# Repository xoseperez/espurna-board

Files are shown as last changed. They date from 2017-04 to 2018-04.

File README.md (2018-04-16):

View this project on [CADLAB.io](https://cadlab.io/node/890). 

# ESPurna Boards

## ESPurna-H

The ESPurna-H board is a custom ESP8266-based smart wall switch. It's singularity is that it's meant to be embedded into the wall behind a standard wall switch, replacing the mechanic switch with a wifi-enabled smart switch.

The board is based on the HLW8012 power monitor IC, the same the Sonoff POW uses.

It features:

* SPDT 10A relay with **NO and NC connections** brought out
* Connections for **external button and notification LED**
* HLW8012 chip for **power monitoring**
* 50x50mm low profile form factor to fit in the wall switch hole

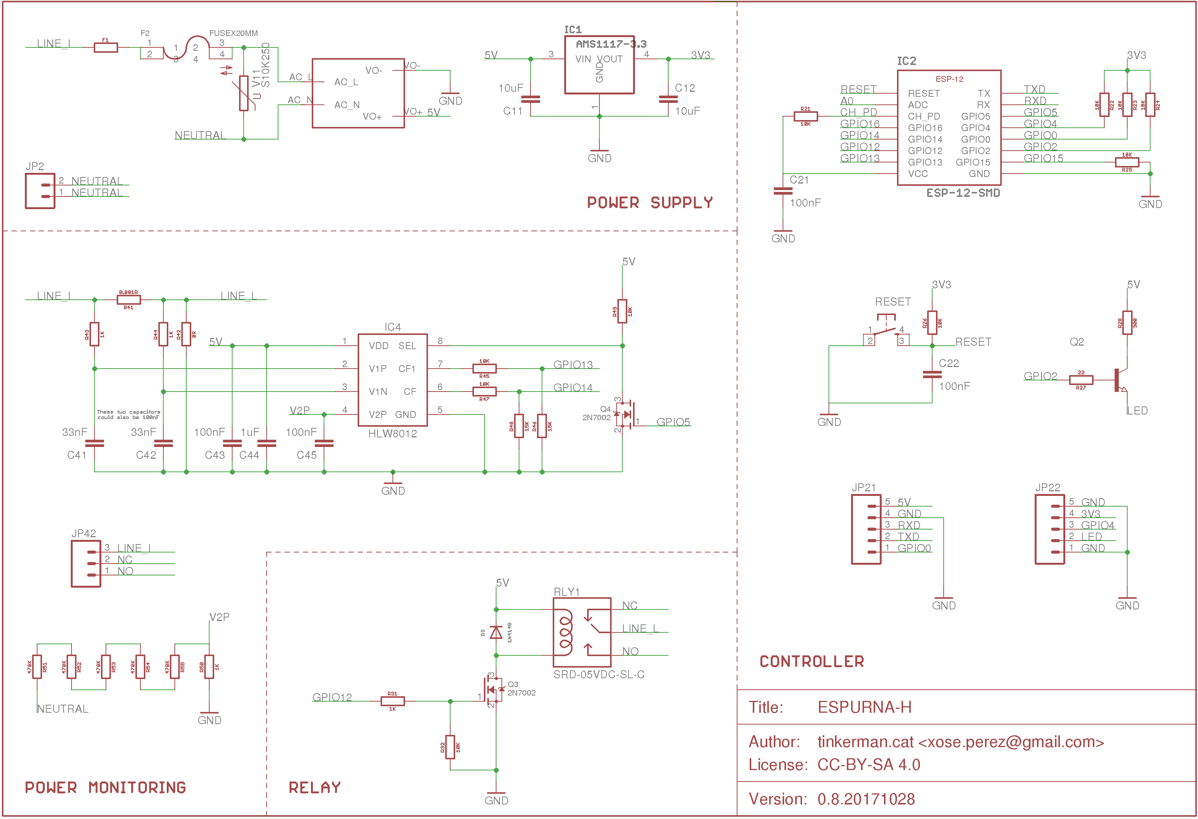
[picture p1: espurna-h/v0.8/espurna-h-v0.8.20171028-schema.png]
ESPurna-H Board - schematic


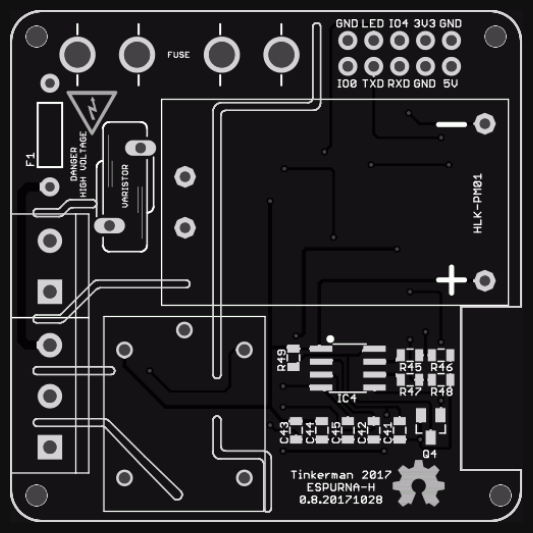
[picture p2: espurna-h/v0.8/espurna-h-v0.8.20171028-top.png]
ESPurna-H Board - layout - top


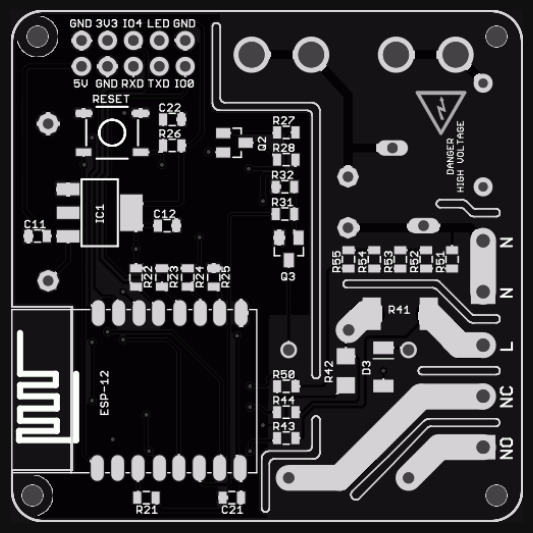
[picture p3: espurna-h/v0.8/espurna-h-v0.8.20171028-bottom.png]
ESPurna-H Board - layout - bottom


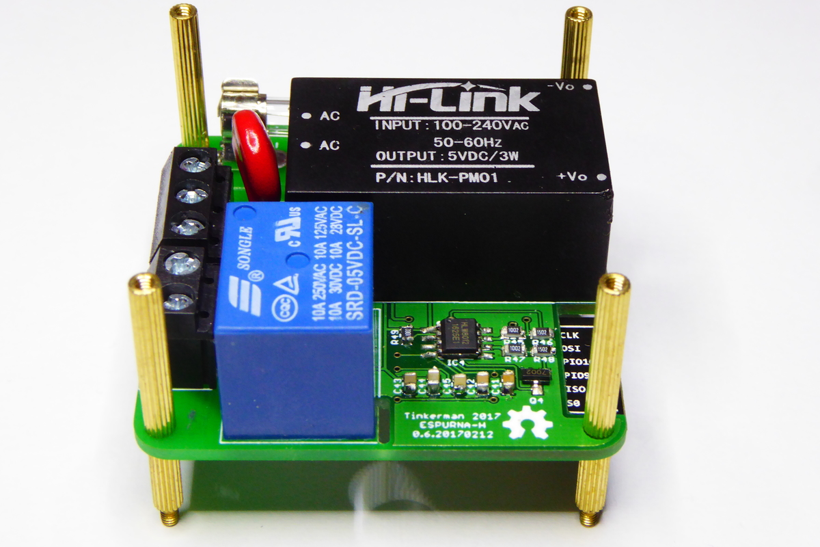
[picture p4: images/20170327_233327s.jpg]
ESPurna-H Board - front view


## Bill of materials

|Item|Location(s)|Buy|Required|Optional <sup>H</sup>|CPU <sup>units</sup>|Total|Total <sup>H</sup>|
|---|---|---|---|---|---|---|---|
|Tinkerman ESPurna-H PCB||[OSH Park](https://oshpark.com/shared_projects/lxVzIaBY)|1||6.50€ <sup>3</sup>|6.50€||
|Ai-Thinker ESP12F|ESP-12|[Aliexpress](http://s.click.aliexpress.com/e/mUZjemI) / [Ebay](https://rover.ebay.com/rover/1/711-53200-19255-0/1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)|1||2.10€ <sup>5</sup>|2.10€||
|Hi-Link HLK-PM01|HLK-PM01|[Aliexpress](http://s.click.aliexpress.com/e/yzVBurN) / [Ebay](https://rover.ebay.com/rover/1/711-53200-19255-0/1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)|1||2.16€ <sup>5</sup>|2.16€||
|Songle SRD-05VDC-SL-C||[Aliexpress](http://s.click.aliexpress.com/e/6Au7qf2) / [Ebay](https://rover.ebay.com/rover/1/711-53200-19255-0/1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)|1||0.39€ <sup>3</sup>|0.39€||
|AMS1117-3.3|IC1|[Aliexpress](http://s.click.aliexpress.com/e/uj6iuNv) / [Ebay](https://rover.ebay.com/rover/1/711-53200-19255-0/1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)|1||0.03€ <sup>50</sup>|0.03€||
|HLW8012|IC4|[Aliexpress](http://s.click.aliexpress.com/e/Fq7URjq)||1|0.72€ <sup>20</sup>||0.72€|
|SF70E 73C thermal fuse|F1|[Aliexpress](http://s.click.aliexpress.com/e/Fq7MFIQ)|1||1.20€ <sup>5</sup>|1.20€||
|Fuse holder|FUSE|[Aliexpress](http://s.click.aliexpress.com/e/uBMfQzR)|1||0.06€ <sup>100</sup>|0.06€||
|500mA 250V fuse|FUSE|[Aliexpress](http://s.click.aliexpress.com/e/Rj2jYB6)|1||0.05€ <sup>100</sup>|0.05€||
|Varistor 270V|VARISTOR|[Aliexpress](http://s.click.aliexpress.com/e/bUjIA2Z)|1||0.18€ <sup>20</sup>|0.18€||
|Push button|RESET|[Aliexpress](http://s.click.aliexpress.com/e/Nzrf6aa)|1||0.02€ <sup>100</sup>|0.02€||
|1N4148 SMD Diode|D3|[Aliexpress](http://s.click.aliexpress.com/e/i2nayrB)|1||0.04€ <sup>100</sup>|0.04€||
|2N7002 SOT-223 N-Mosfet|Q2, Q3, Q4|[Aliexpress](http://s.click.aliexpress.com/e/yFQnA2J)|2|1|0.05€ <sup>50</sup>|0.10€|0.05€|
|10uF 0805 tantalum capacitor|C11, C12||2||0.01€ <sup>100</sup>|0.02€||
|100nF 0805 ceramic capacitor|C21, C22, C43, C45||2|2|0.01€ <sup>100</sup>|0.02€|0.02€|
|33nF 0805 ceramic capacitor|C41, C42|||2|0.01€ <sup>100</sup>||0.02€|
|1uF 0805 ceramic capacitor|C44|||1|0.01€ <sup>100</sup>||0.01€|
|0.001 2512 Ohm resistor|R41|[Aliexpress](http://s.click.aliexpress.com/e/fIaA6QB)||1|0.03€ <sup>10</sup>||0.03€|
|0 Ohm 1206 resistor|R42|[Aliexpress](http://s.click.aliexpress.com/e/jEAqfqb)||1|0.01€ <sup>500</sup>||0.01€|
|22Ohm 0805 resistor|R27||1||0.01€ <sup>100</sup>|0.01€||
|300Ohm 0805 resistor|R28||1||0.01€ <sup>100</sup>|0.01€||
|1KOhm 0805 resistor|R31, R43, R44, R50||1|3|0.01€ <sup>100</sup>|0.01€|0.03€|
|10KOhm 0805 resistor|R21, R22, R23, R24,<br />R25, R26, R32, R45,<br />R47, R49||7|3|0.01€ <sup>100</sup>|0.07€|0.03€|
|15KOhm 0805 resistor|R46, R48|||2|0.01€ <sup>100</sup>||0.02€|
|470KOhm 0805 resistor|R51, R52, R53, R54,<br />R55|||5|0.01€ <sup>100</sup>||0.05€|
|2 positions 5mm screw terminal||[Aliexpress](http://s.click.aliexpress.com/e/a2fqnM7)|1||0.06€ <sup>100</sup>|0.06€||
|3 positions 5mm screw terminal||[Aliexpress](http://s.click.aliexpress.com/e/Vjaa2RB)|1||0.07€ <sup>100</sup>|0.07€||
|5x2 position male header|||1||0.01€ <sup>100</sup>|0.01€||
|**Total**||||||13.11€|0.97€|

* (H) Optional, only required for power monitor.
* (units) Minimum quantity for the stated price.
* Prices are based on the cheapest option, usually Aliexpress.
* Check the schematic (image or eagle file) for relation between parts and values.

## Firmware

NOTE: PLEASE NOTE THAT IT IS A REQUIREMENT OF THE HLW8012 POWER MONITOR CHIP TO TIE THE POWER LINE TO THE CIRCUIT GROUND. THIS MEANS THAT YOU SHOULD NEVER EVER CONNECT THE BOARD GROUND TO YOUR COMPUTER WHILE CONNECTED TO MAINS. NEVER EVER FLASH THE BOARD WHILE CONNECTED TO MAINS!!

The ESPurna board is named after the [ESPurna firmware](https://bitbucket.org/xoseperez/espurna) which features:

* Support for multiple ESP8266-based boards (check list)
* Support for up to 5 different network configurations
* Support for different types of switches and different options (pulses, synchronization,..)
* **MQTT** enabled
* **Alexa integration** using the FauxmoESP Library
* **Domoticz** integration via MQTT
* **Home Assistant** integration via MQTT
* Support for different **sensors** (DHT22, DS18B20, HLW8012, current sensors, analog sensors,...)
* Fast asynchronous **HTTP Server**
* Backup and restore settings option
* Upgrade firmware from the web interface
* **REST API** (enable/disable from web interface)
* **Over-The-Air** (OTA) updates
* ... and much more

## Open Hardware

Hardware designs (schematics and CAD) files are licensed under the [Creative Commons Attribution-ShareAlike 3.0 Unported License](http://creativecommons.org/licenses/by-sa/3.0/) and follow the terms of the [OSHW (Open-source hardware) Statement of Principles 1.0.](http://freedomdefined.org/OSHW)

## Disclaimer

THIS PRODUCT IS TARGETED TO EXPERIENCED USERS AT THEIR OWN RISK. THIS PRODUCT IS MEANT TO BE USED PLUGGED TO MAINS AND IT REQUIRES A DEEP UNDERSTANDING OF THE PERILS OF HIGH VOLTAGE ON HUMAN LIFE.

TO THE FULLEST EXTENT PERMISSIBLE BY THE APPLICABLE LAW, I HEREBY DISCLAIM ANY AND ALL RESPONSIBILITY, RISK, LIABILITY AND DAMAGES ARISING OUT OF DEATH OR PERSONAL INJURY RESULTING FROM ASSEMBLY OR OPERATION OF THIS PRODUCT.

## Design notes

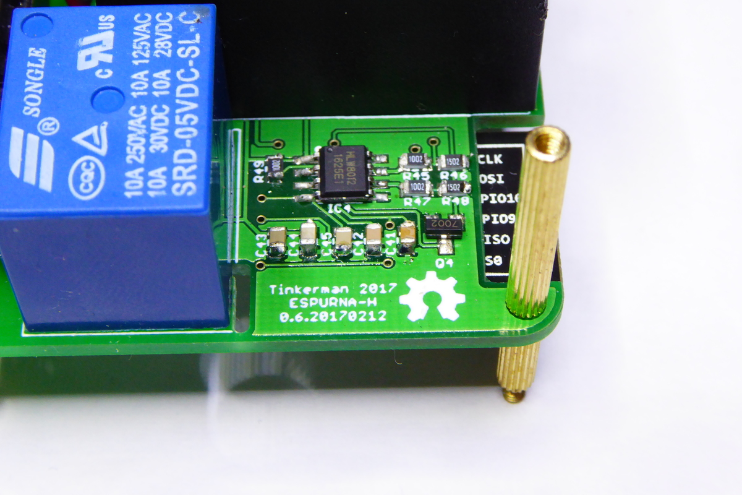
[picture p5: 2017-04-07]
images/20170327_233238s.jpg

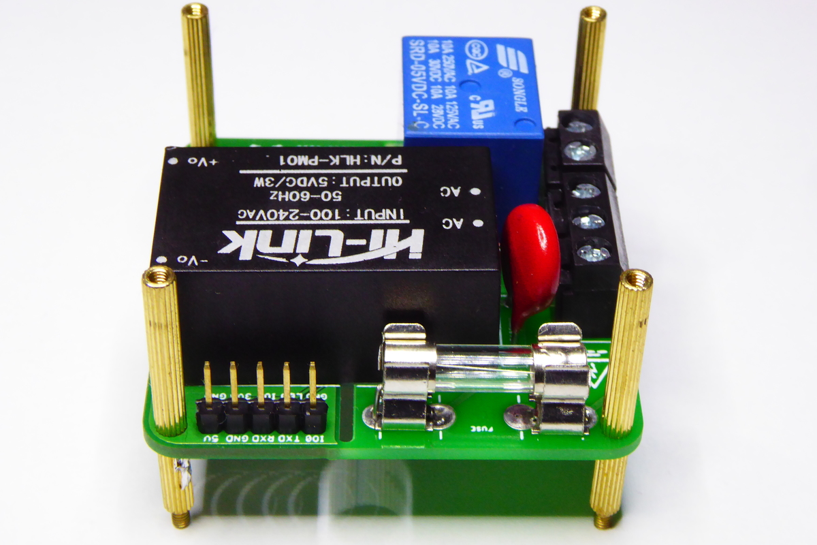
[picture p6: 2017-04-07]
images/20170327_233321s.jpg

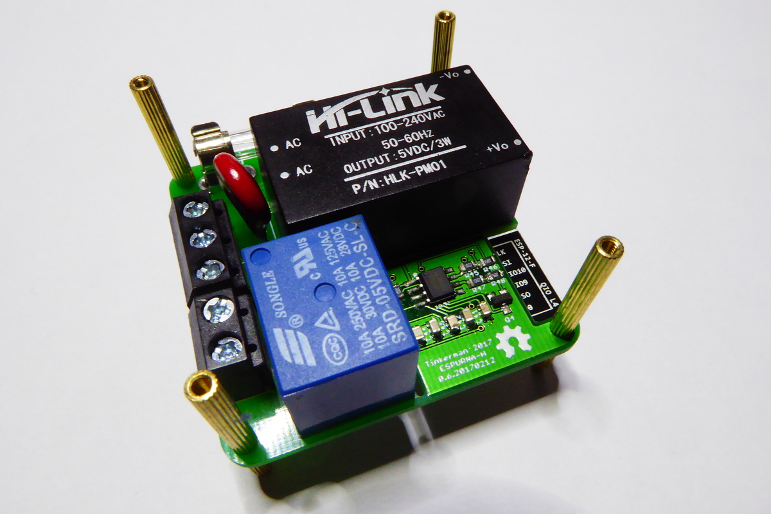
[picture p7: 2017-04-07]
images/20170327_233139s.jpg

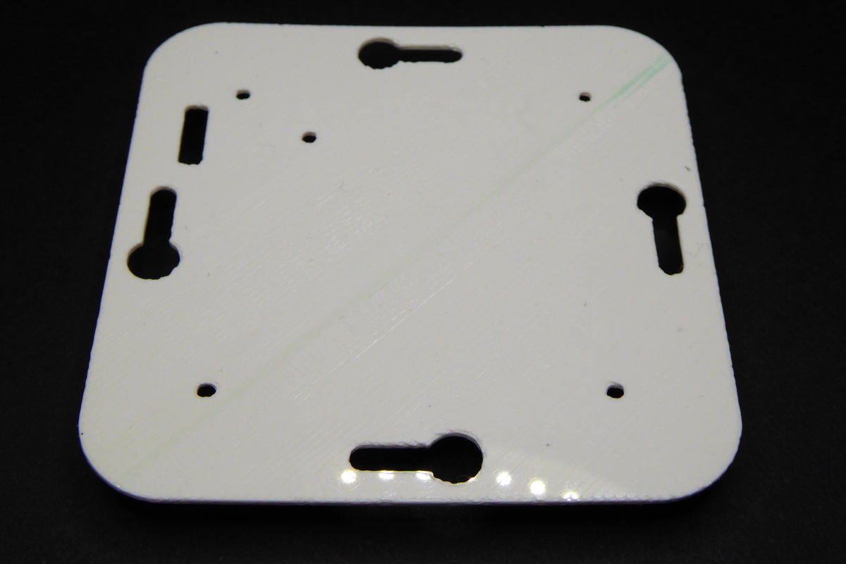
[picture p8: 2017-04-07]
images/20170406_110328s.jpg

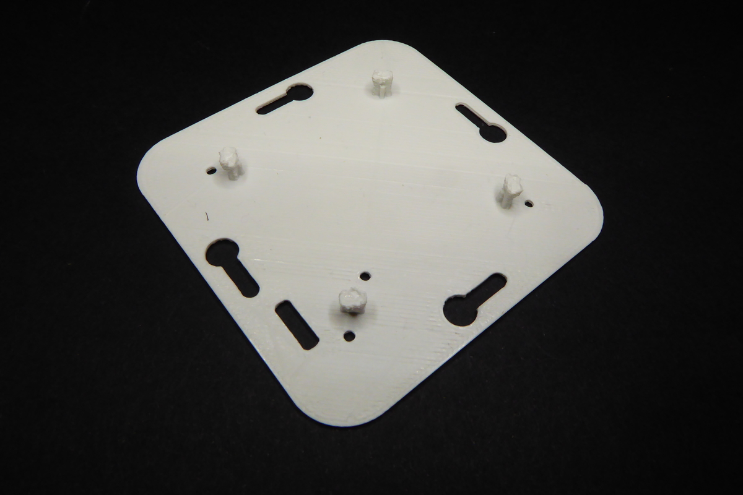
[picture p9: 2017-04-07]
images/20170406_110257s.jpg

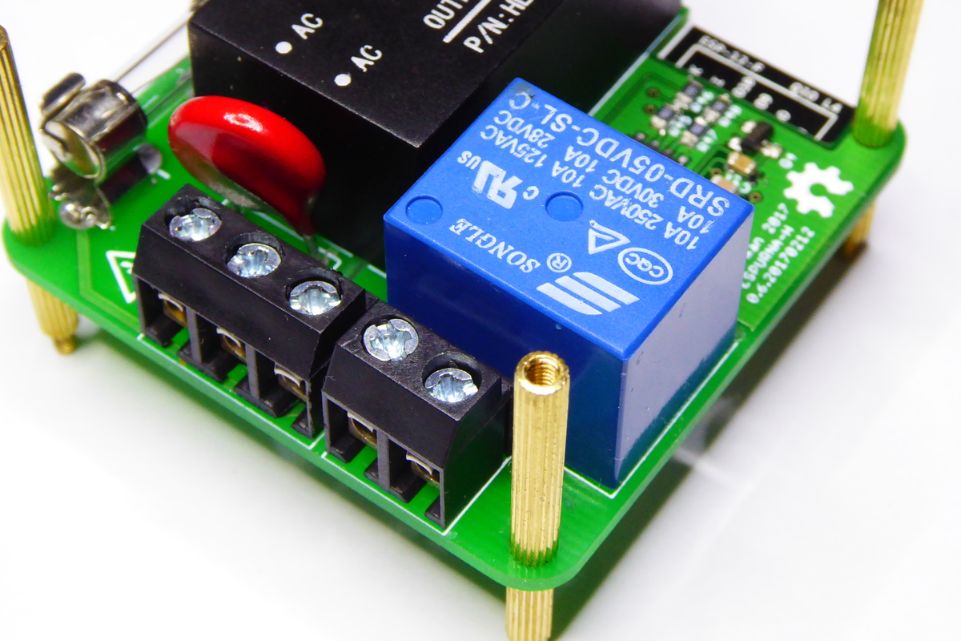
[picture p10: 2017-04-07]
images/20170327_233301s.jpg

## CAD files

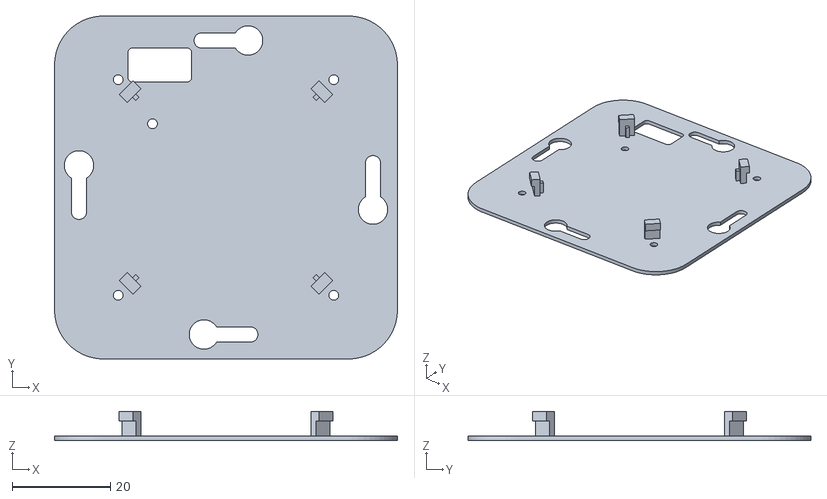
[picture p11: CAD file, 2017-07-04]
parts/espurna-base-v2.stl
70.0 x 70.0 x 6.00

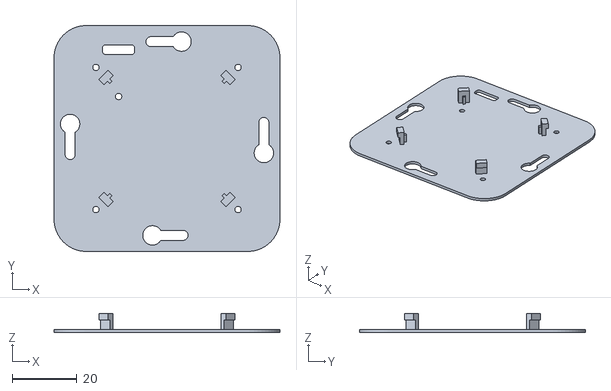
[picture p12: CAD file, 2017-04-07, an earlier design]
parts/espurna-base.stl
70.0 x 70.0 x 6.00

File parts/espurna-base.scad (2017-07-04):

//-----------------------------------
// CONFIGURATION
//-----------------------------------

size=70;
corner=10;

//-----------------------------------


module base() {
    
    offset = (2 * corner - size) / 2;
    hole_vector = sqrt(22*22*2);
    
    difference() {
        
        // base
        translate([offset, offset]) {
            minkowski() {
                square(size-2 * corner);
                circle(corner, $fn=50);
            }
        }
        
        // PCB holes
        for(i = [45:90:315]) {
            rotate([0,0,i]) {
                translate([0,hole_vector]) {
                    circle(1, $fn=50);
                }
            }
        }
        
        // wall holes
        for(i = [0:90:270]) {
            rotate([0,0,i]) {
                translate([0,30]) {
                    translate([4.5,0]) circle(3, $fn=50);
                    minkowski() {
                        square([10,0.1], true);
                        circle(1.5, $fn=50);
                    }
                }
            }
        }
        
        // reset hole
        translate([7-22,22-9]) {
            circle(1, $fn=50);
        }
        
        // headers panel v2
        translate([-19,22.5]) {
            minkowski() {
                square([11,5], false);
                circle(1, $fn=50);
            }
        }
        
    }
}

module pastilla() {
    rotate([0,0,90]) {
        translate([-0.75, -2]) {
            union() {
                linear_extrude(5) square([1.5,4], false);
                translate([0,0,3]) linear_extrude(2) {
                    square([2.3,4], false);
                }
                linear_extrude(3) translate([-0.5,2]) square([1,1], true);
            }
        }
    }
}

module 3d() {
    
    thickness = 1;
    pastilla_vector = sqrt(19.3*19.3*2);
    
    union() {

        linear_extrude(thickness) base();

        //pastillas
        for(i = [45:90:315]) {
            rotate([0,0,i]) {
                translate([0,pastilla_vector,thickness]) {
                    pastilla();
                }
            }
        }
    }
}

//base();
3d();
//pastilla();

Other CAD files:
parts/espurna-base.dxf

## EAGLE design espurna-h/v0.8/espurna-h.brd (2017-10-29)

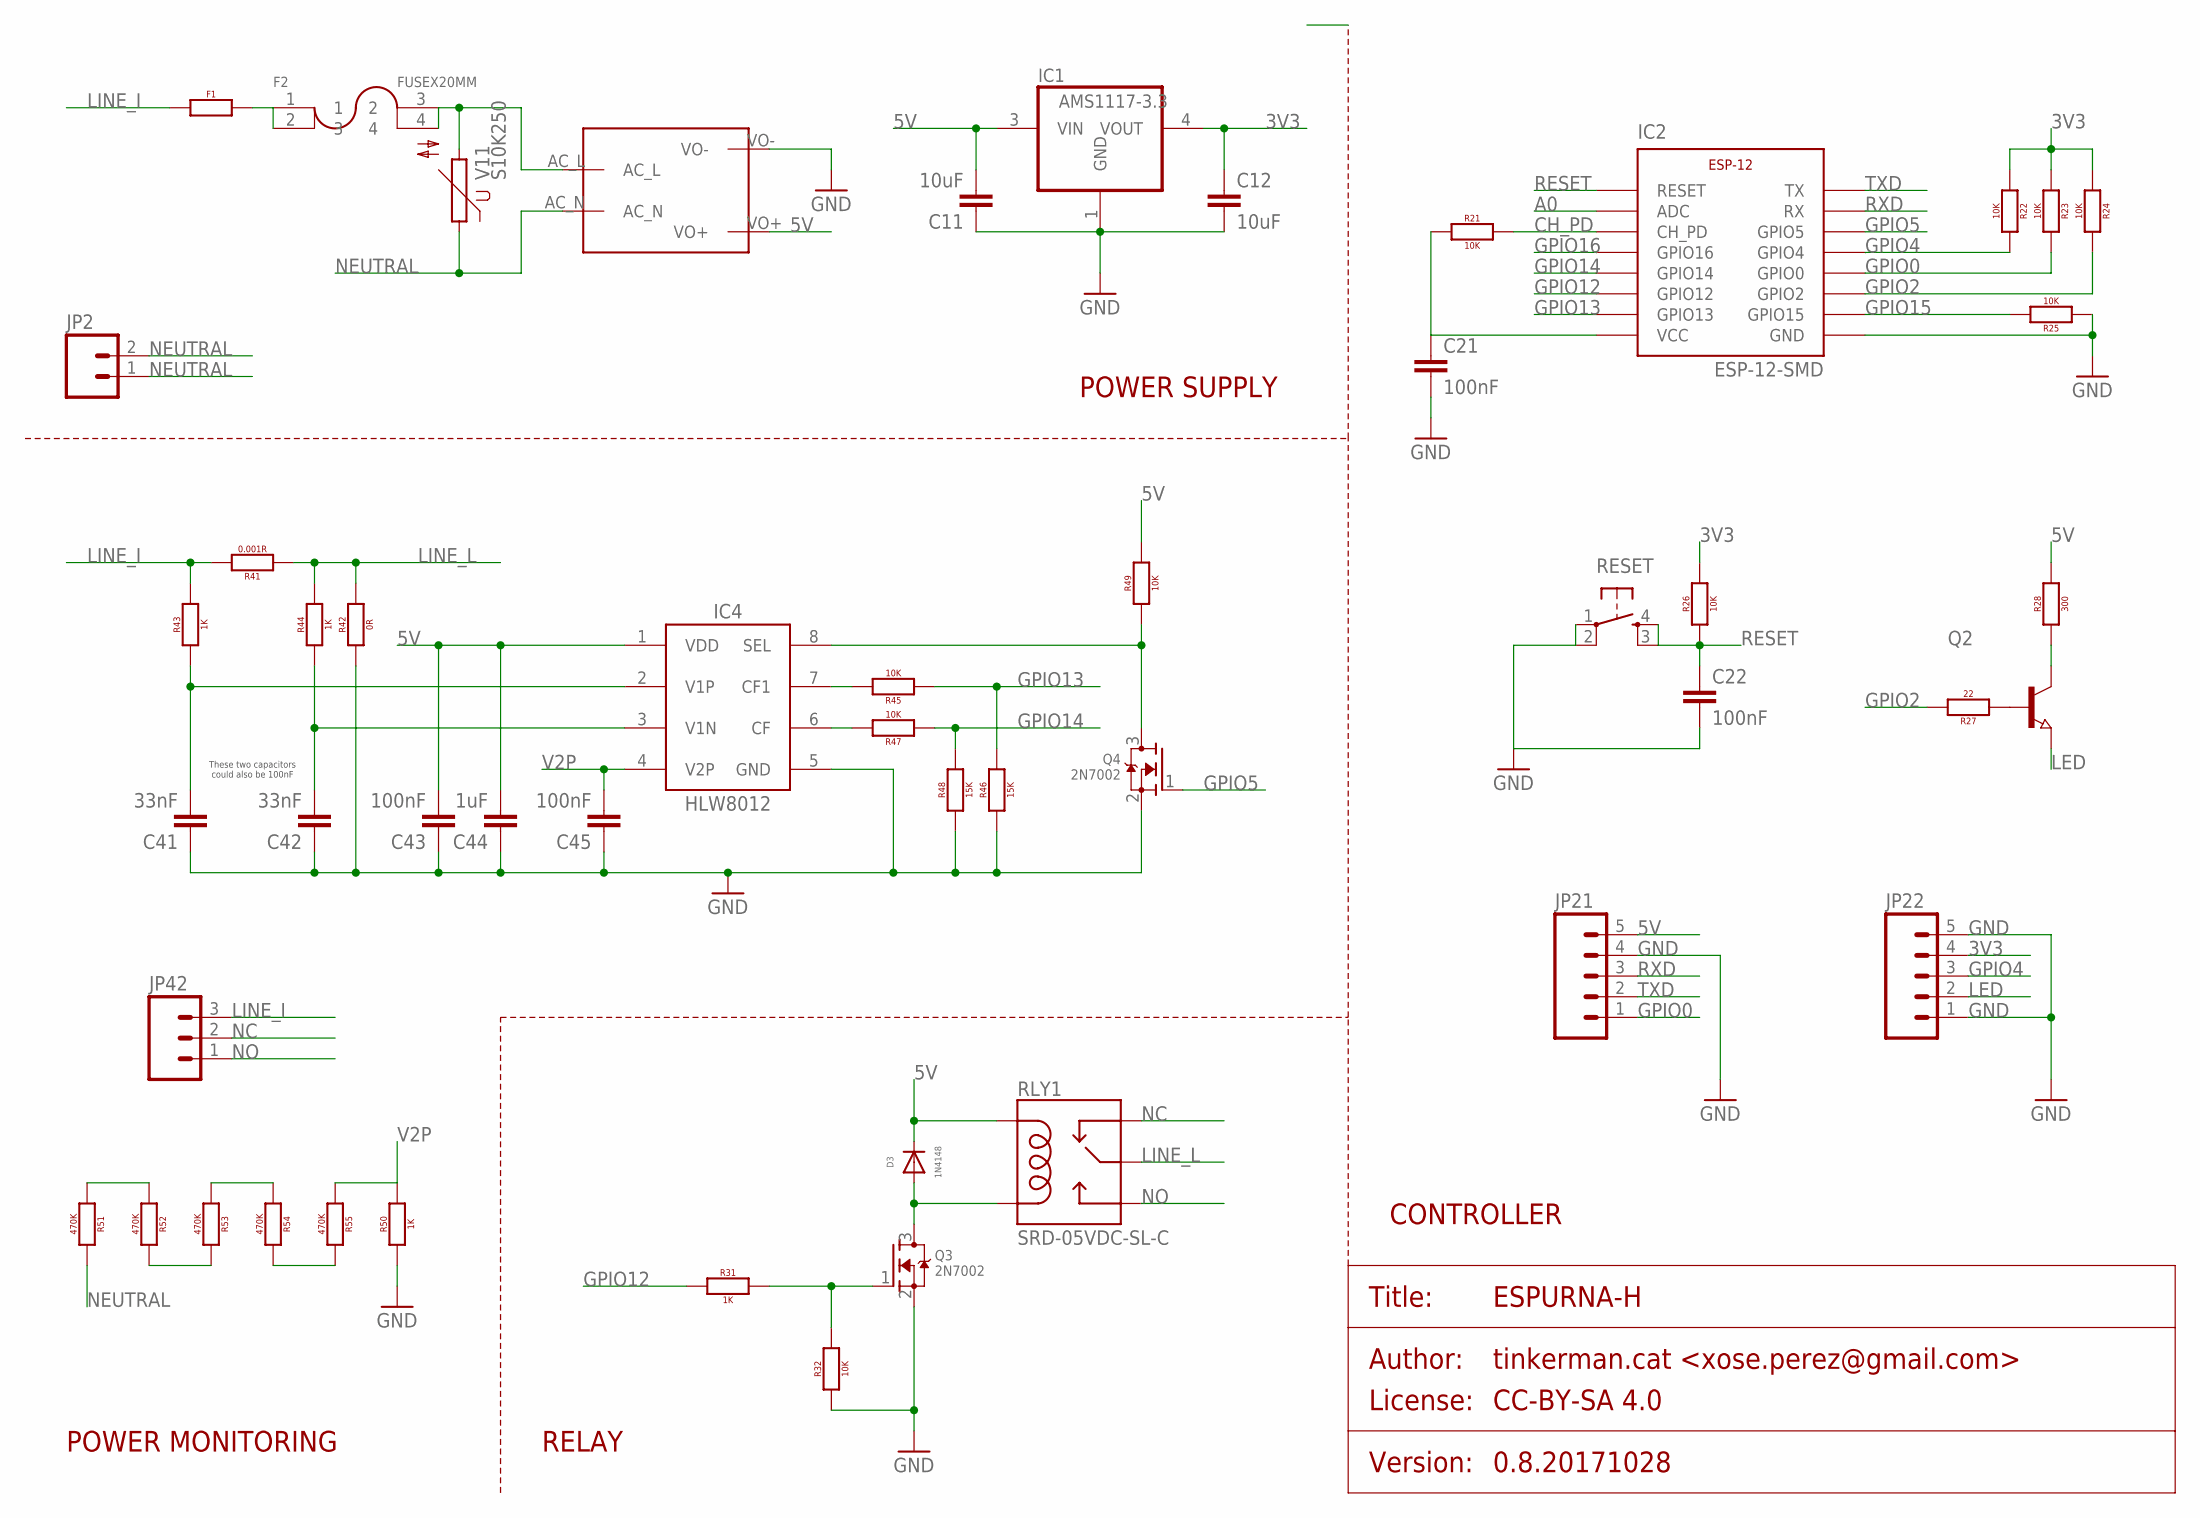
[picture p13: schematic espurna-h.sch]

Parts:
C11, C12: 10uF; 0805
C21, C22, C43, C45: 100nF; 0805
C41, C42: 33nF; 0805
C44: 1uF; 0805
D3: 1N4148; SOD80
F1: THERMALFUSE0.4; AXIAL-0.4
F2: FUSEX20MM; FUSE_5MM
IC1: AMS1117-3.3; SOT223
IC2: ESP-12-SMD
IC4: HLW8012; SOP8
JP2: M02200MIL; SCREWTERMINAL-200MIL-2
JP21, JP22: M05PTH; 1X05
JP42: M03200MIL; SCREWTERMINAL-200MIL-3
Q2: NPN-TRANSISTOR_SOT23; SOT23
Q3, Q4: 2N7002; SOT23
R21, R22, R23, R24, R25, R26, R32, R45, R47, R49: 10K; 0805
R27: 22; 0805
R28: 300; 0805
R31, R43, R44, R50: 1K; 0805
R41: 0.001R; 2512
R42: 0R; 1206
R46, R48: 15K; 0805
R51, R52, R53, R54, R55: 470K; 0805
RESET: TACTILE_BUTTON_SMD; TACTILE-BUTTON-SMD
RLY1: SRD-05VDC-SL-C; SRD-5VDC-SL-C
U$1: MAINS_CONVERTERS; HLK-PM01
V11: S10K250

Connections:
3V3: C12.1, C21.1, IC1.4 (VOUT), IC2.VCC, JP22.4, R21.1, R22.1, R23.1, R24.1, R26.2
5V: C11.2, C43.2, C44.2, D3.2 (C), IC1.3 (VIN), IC4.1 (VDD), JP21.5, R28.2, R49.2, RLY1.COIL1, U$1.VO+
A0: IC2.ADC
CH_PD: IC2.CH_PD, R21.2
GND: C11.1, C12.2, C21.2, C22.2, C41.1, C42.1, C43.1, C44.1, C45.1, IC1.1 (GND), IC2.GND, IC4.5 (GND), JP21.4, JP22.1, JP22.5, Q3.2 (S), Q4.2 (S), R25.1, R32.1, R42.1, R46.1, R48.1, R50.1, RESET.1 (SWA1), RESET.2 (SWB1), U$1.VO-
GPIO0: IC2.GPIO0, JP21.1, R23.2
GPIO2: IC2.GPIO2, R24.2, R27.2
GPIO4: IC2.GPIO4, JP22.3, R22.2
GPIO5: IC2.GPIO5, Q4.1 (G)
GPIO12: IC2.GPIO12, R31.1
GPIO13: IC2.GPIO13, R45.1, R46.2
GPIO14: IC2.GPIO14, R47.1, R48.2
GPIO15: IC2.GPIO15, R25.2
GPIO16: IC2.GPIO16
LED: JP22.2, Q2.2 (E)
LINE_I: F1.P$1 (1), JP42.3, R41.2, R43.2
LINE_L: R41.1, R42.2, R44.2, RLY1.COMMON (MAIN)
LINE_P: F2.3 (2), F2.4, U$1.AC_L, V11.2
unnamed: Q2.3 (C), R28.1
unnamed: Q2.1 (B), R27.1
unnamed: D3.1 (A), Q3.3 (D), RLY1.COIL2
unnamed: Q3.1 (G), R31.2, R32.2
unnamed: R51.1, R52.1
unnamed: F1.P$2 (2), F2.1, F2.2 (3)
unnamed: R52.2, R53.2
unnamed: IC4.8 (SEL), Q4.3 (D), R49.1
unnamed: IC4.7 (CF1), R45.2
unnamed: C41.2, IC4.2 (V1P), R43.1
unnamed: IC4.6 (CF), R47.2
unnamed: C42.2, IC4.3 (V1N), R44.1
unnamed: R53.1, R54.1
unnamed: R54.2, R55.2
NC: JP42.2, RLY1.CLOSED (NC)
NEUTRAL: JP2.1, JP2.2, R51.2, U$1.AC_N, V11.1
NO: JP42.1, RLY1.OPEN (NO)
RESET: C22.1, IC2.RESET, R26.1, RESET.3 (SWB2), RESET.4 (SWA2)
RXD: IC2.RX, JP21.3
TXD: IC2.TX, JP21.2
V2P: C45.2, IC4.4 (V2P), R50.2, R55.1

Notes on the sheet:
POWER SUPPLY
RELAY
CONTROLLER
POWER MONITORING
These two capacitors could also be 100nF

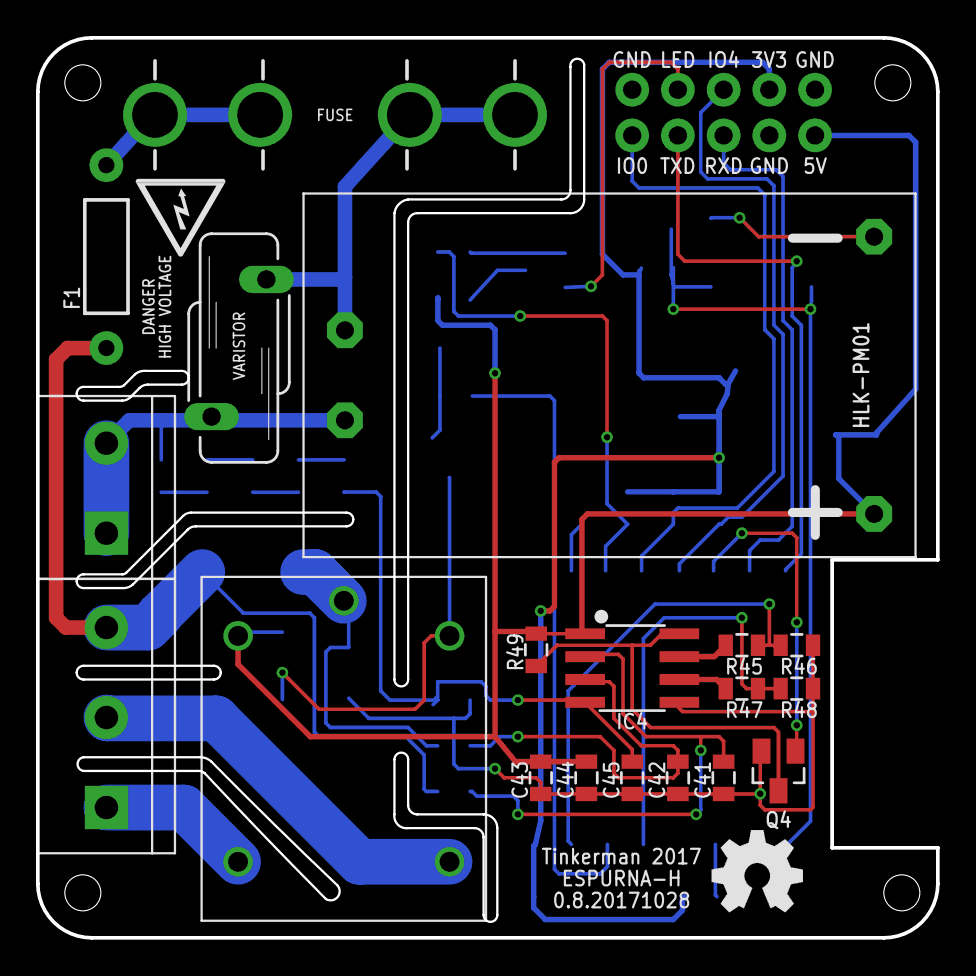
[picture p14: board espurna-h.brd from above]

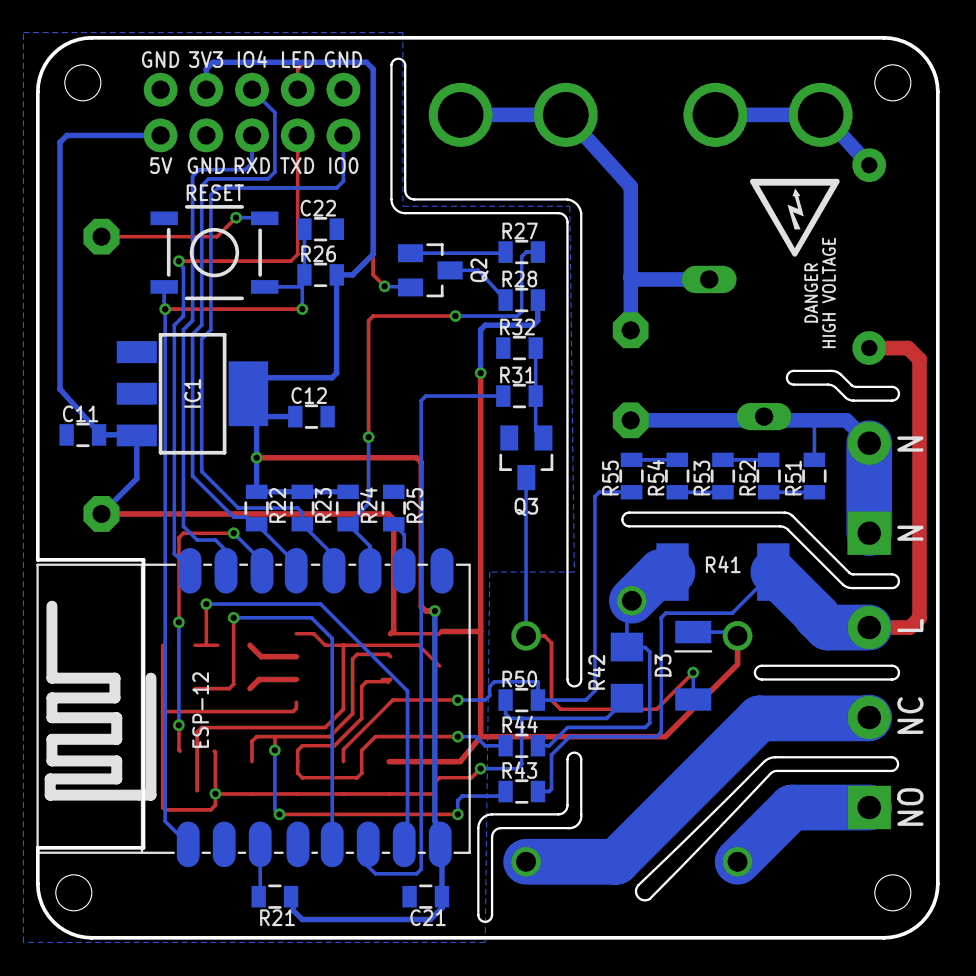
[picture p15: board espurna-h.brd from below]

Board: 2 copper layers, 50.0 x 50.0 mm, 55 parts (30 on the bottom side), 37 nets.

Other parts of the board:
U$2, U$3, U$4, U$5: HOLE_M2_WIDE

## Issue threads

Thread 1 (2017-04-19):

Optoisolator is unnecessary

jaseg, 2017-04-19:
As the design is non-isolated anyway and also the relay already provides a fair amount of isolation *and* is powered from the same rail anyway, the optoisolator is completely redundant.

krisnadn11, 2023-11-23:
Can you explain in more detail about this?

Because relays sold in the market generally use an Optocoupler circuit (PC-817C). As far as I know, this semiconductor is used to provide good galvanic isolation between the control section and the power section of the relay. This galvanic isolation helps protect the control circuit from high voltages or currents that may be present on the power circuit.

Closed 2023-11-23.

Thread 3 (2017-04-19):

Maybe use capacitive dropper instead of isoltated power supply

jaseg, 2017-04-19:
Since the design is not isolated in any case with GND being tied to phase (L), an inexpensive capacitive dropper would suffice instead of the expensive and error-prone isolated SMPS.

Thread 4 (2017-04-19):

0805 resistors likely operated out of their voltage spec

jaseg, 2017-04-19:
Some 0805 resistors, particularly R43 and R44 may under fault conditions (e.g. in case of a fault of the power measurement chip) be operated beyond the typical 150V MAX rating of 0805 resistors.

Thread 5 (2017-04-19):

Varistor and fuse do not protect current measurement circuitry

jaseg, 2017-04-19:
IMHO it would make sense to put the power measurement circuitry behind the fuse/varistor protection.

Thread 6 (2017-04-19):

Top right hole too close to fuse holder pad

jaseg, 2017-04-19:
Hexagonal standoffs are pretty common and much wider than the knurled round standoffs displayed on the pictures. Due to the fuse holder effectively ending in the middle of the large round pad if someone would use hex standoffs on the board they might unknowingly have them going live from contact with the fuse holder pad, which may potentially be very bad if the standoffs are electrically connected to any externally accessible screws or a conductive case.

A large cutout around the standoff holes would fix this.

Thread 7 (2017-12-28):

SF70E 73C thermal fuse holes are small, and fuse does not fit properly

bgupta55, 2017-12-28:

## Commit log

2017-04-07 Fix BOM table
2017-04-07 Updated BOM
2017-04-07 Licensed CC-BY-SA 3.0
    [espurna-h.sch]
2017-07-04 Swapped GPIO2 and GPIO5 to avoid the module LED to change with HLW8012 SEL pin value
    [espurna-h.brd, espurna-h.sch]
2017-07-04 Relocate header window in base 3D model
    [espurna-base-v2.stl, espurna-base.scad]
2017-07-04 Change varistor symbol, added thermal fuse, change measurement point
    [espurna-h.brd, espurna-h.sch]
2017-09-13 Save eagle files for v0.6
    [espurna-h.brd, espurna-h.sch]
2017-09-13 Separate power from load. Wire
    [espurna-h.brd, espurna-h.sch]
2017-09-14 Version 0.7.20170913
    [espurna-h.brd, espurna-h.sch]
2017-10-09 Freeze 0.7
    [espurna-h.brd, espurna-h.sch]
2017-10-29 ESPurna H version 0.8.20171028
    [espurna-h.brd, espurna-h.sch]
2017-10-29 ESPurna Board 0.8

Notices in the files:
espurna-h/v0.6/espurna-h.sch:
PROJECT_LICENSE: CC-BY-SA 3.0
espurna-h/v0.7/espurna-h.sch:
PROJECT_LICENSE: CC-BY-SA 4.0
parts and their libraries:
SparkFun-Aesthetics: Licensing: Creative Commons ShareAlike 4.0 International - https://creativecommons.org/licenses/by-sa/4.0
